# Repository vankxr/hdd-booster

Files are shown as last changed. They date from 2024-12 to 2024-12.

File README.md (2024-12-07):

# hdd-booster
This project consists of a simple PCB with two switching step-down regulators.
It aims to solve, or at least mitigate the low +5V rail current capacity of newer ATX consumer power supplies, which is a problem when trying to power lots of HDDs.
This problem is aggravated when adapters and splitters are used to expand the number of SATA/Molex power connectors.

## Short description
The board accepts power via a PCIe +12V aux power connector.
Since this board is best used on a NAS, typically there won't be any GPU installed, and thus there will be a +12V PCIe connector available.
The 12V from the PSU feeds both step-down regulators. Each regulator is capable of supplying about 5A, which should be enough for 4 power hungry HDDs.

## Authors

* **João Silva** - [vankxr](https://github.com/vankxr)

## License

The content of this repository is licensed under the [GNU General Public License v3.0](LICENSE).

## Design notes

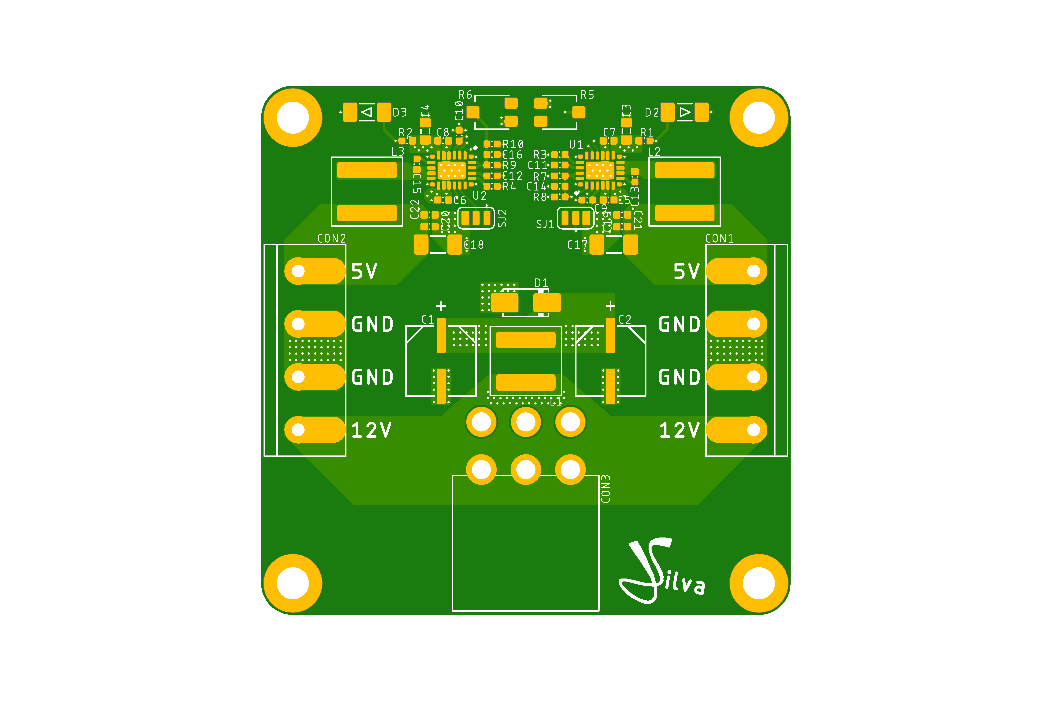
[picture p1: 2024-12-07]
pcb/hdd-booster-top.png

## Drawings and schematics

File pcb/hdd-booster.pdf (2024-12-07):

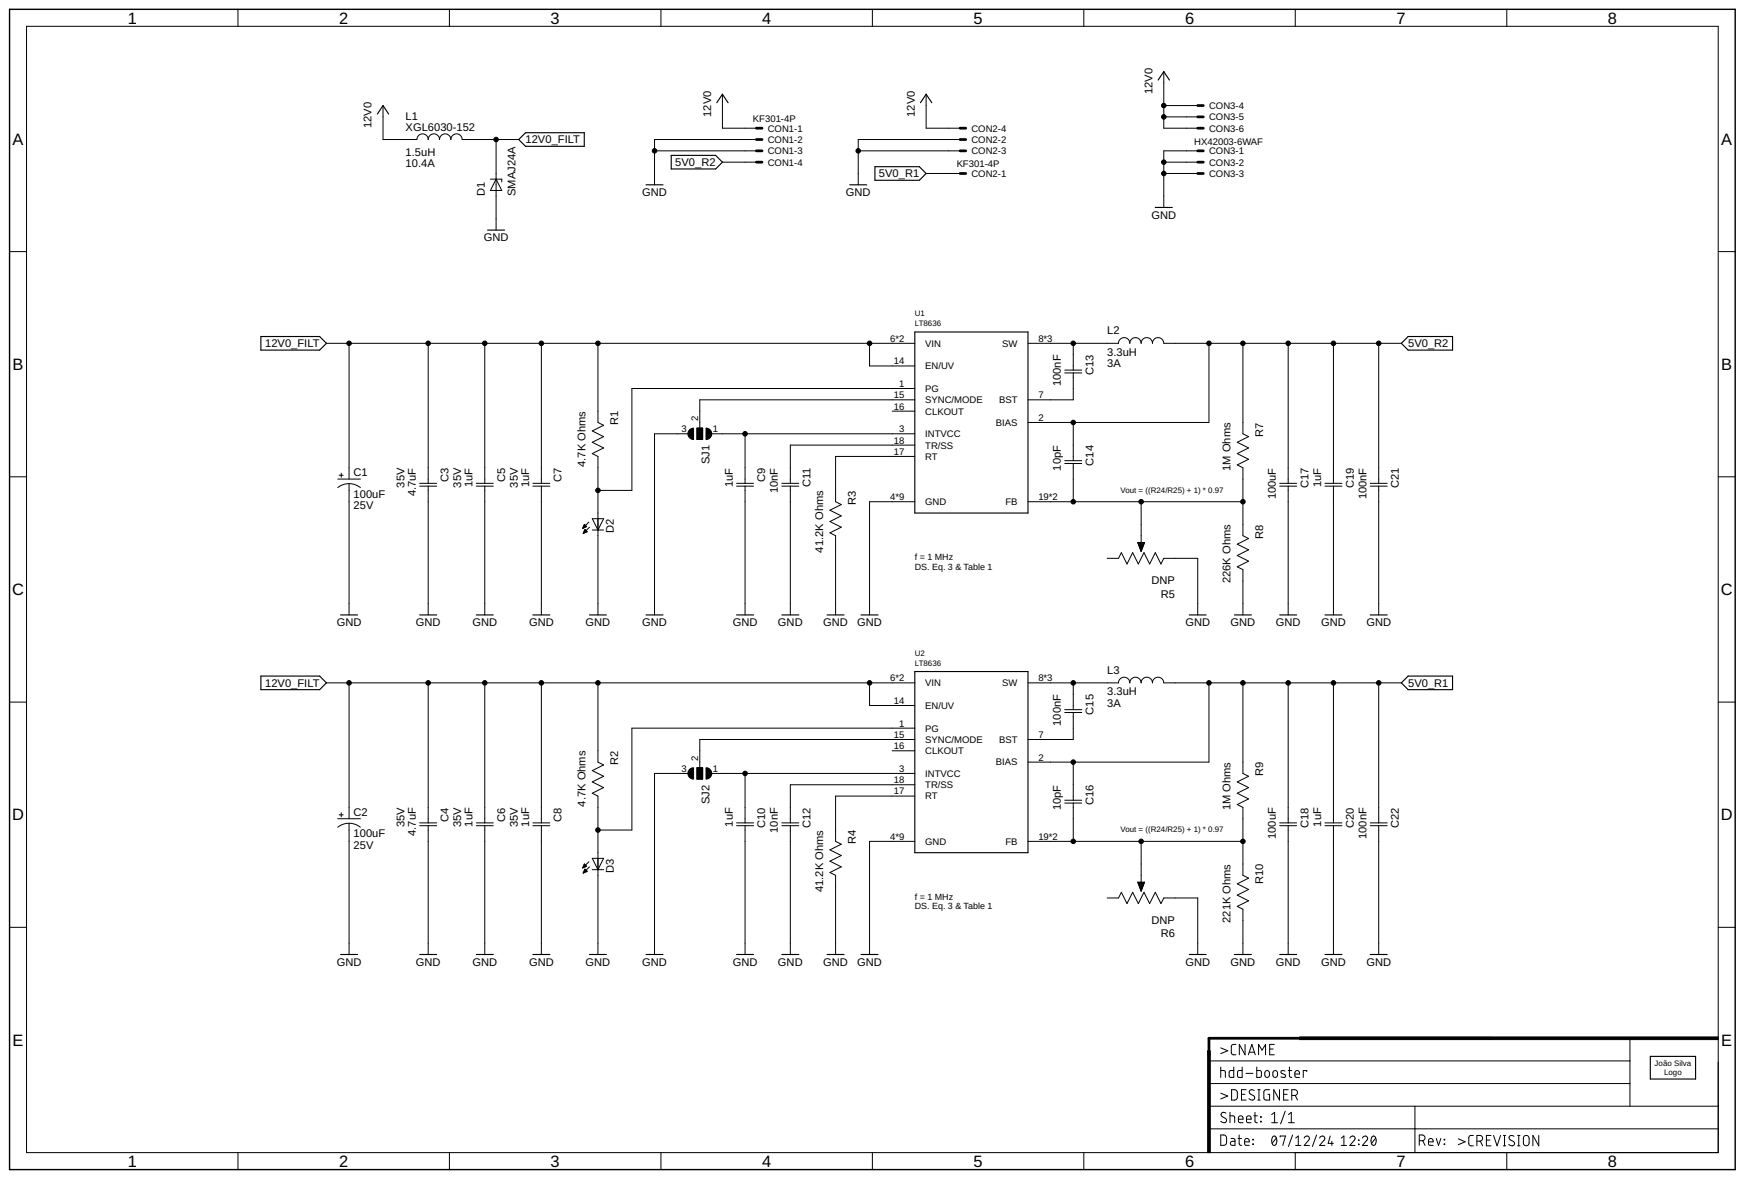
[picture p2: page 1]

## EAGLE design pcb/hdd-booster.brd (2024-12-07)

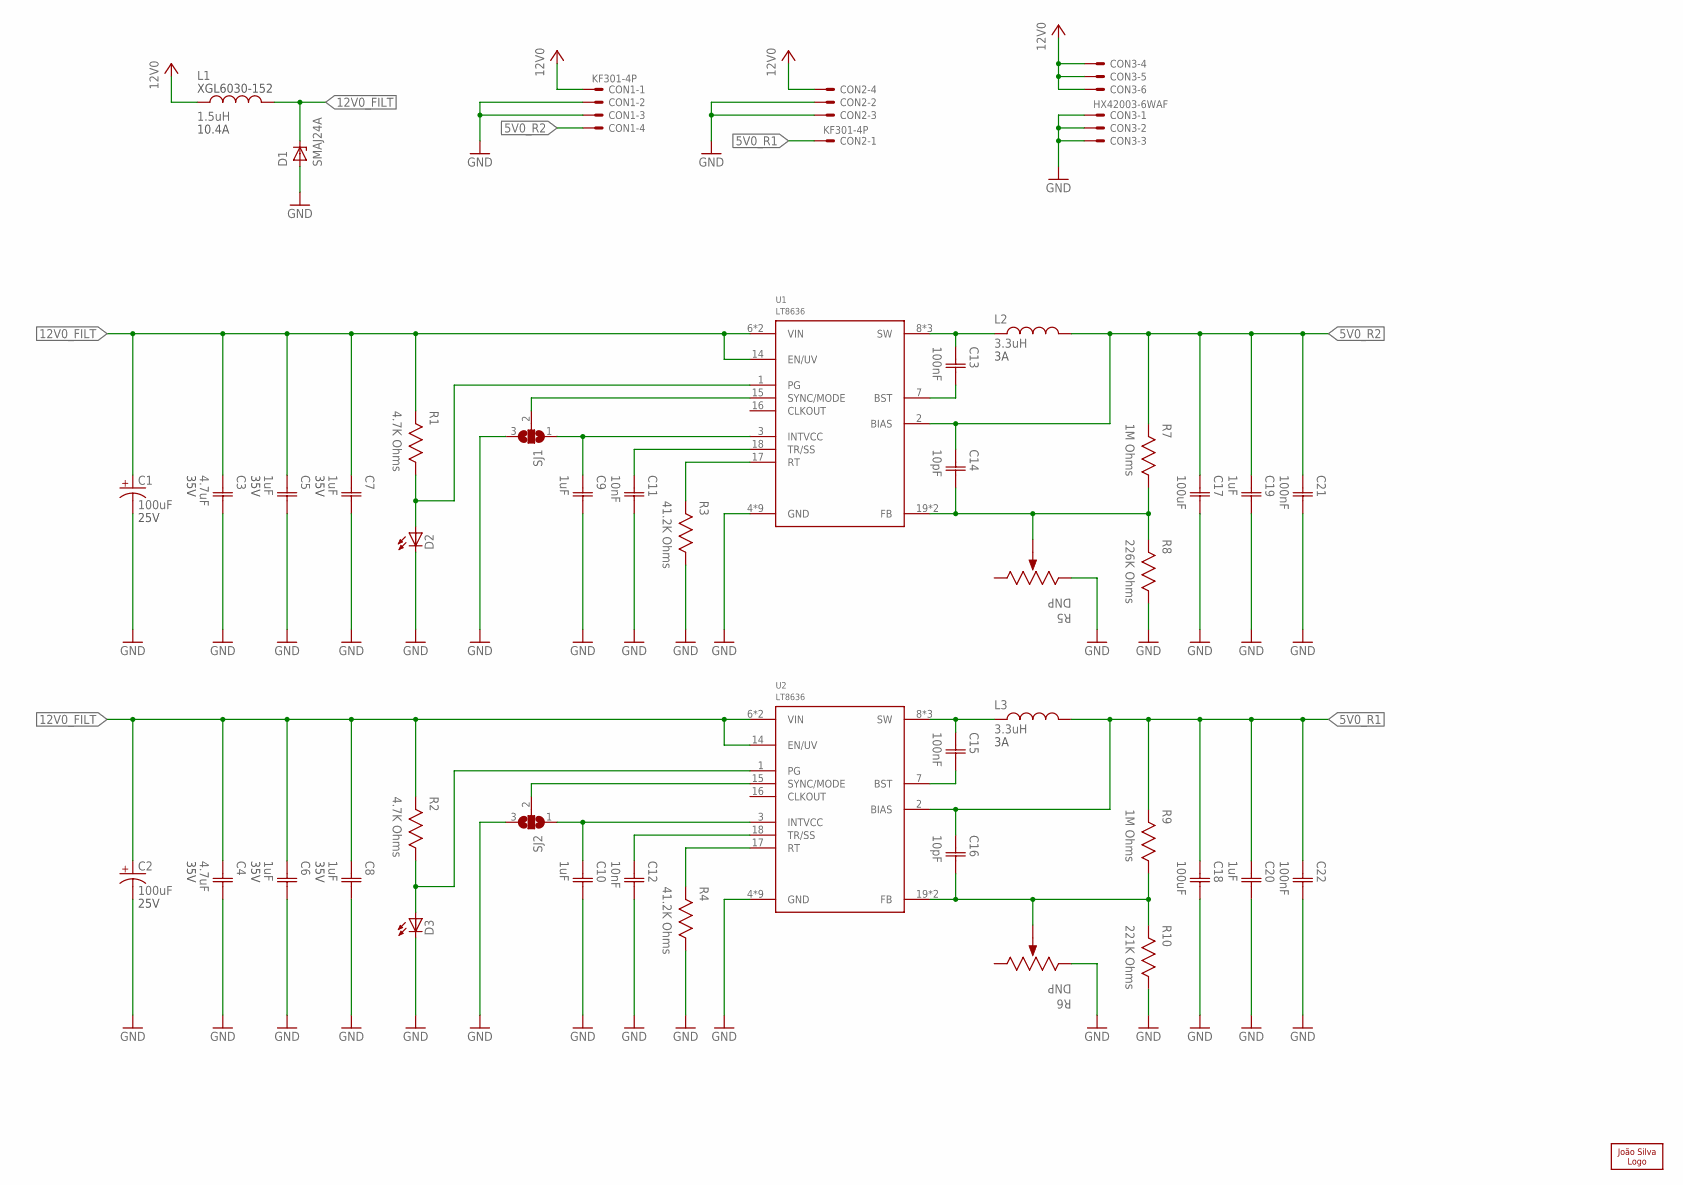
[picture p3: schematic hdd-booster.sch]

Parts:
C1, C2: 100uF; AL-CAP-CASE-D; VOLTAGE 25V
C3, C4: 4.7uF; CAP0603; VOLTAGE 35V
C5, C6, C7, C8: 1uF; CAP0402; VOLTAGE 35V
C9, C10, C19, C20: 1uF; CAP0402
C11, C12: 10nF; CAP0402
C13, C15, C21, C22: 100nF; CAP0402
C14, C16: 10pF; CAP0402
C17, C18: 100uF; CAP1206
CON1, CON2: KF301-4P
CON3: HX42003-6WAF
D1: SMAJ24A; DO214AC
D2, D3: LED1206; 1206
L1: 1.5uH; XGL6030
L2, L3: 3.3uH; XGL6030
LOGO1: JSILVA-5MM; JSILVA_5MM
R1, R2: 4.7K Ohms; RES0402
R3, R4: 41.2K Ohms; RES0402
R5, R6: DNP; POT3MM
R7, R9: 1M Ohms; RES0402
R8: 226K Ohms; RES0402
R10: 221K Ohms; RES0402
SJ1, SJ2: SJ2S; SJ2_S
U1, U2: LT8636; QFN20_ASYM_3X4_CORNER

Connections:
5V0_R1: C16.1 (C1), C18.1 (C1), C20.1 (C1), C22.1 (C1), CON2.1, L3.2, R9.2, U2.2 (BIAS)
5V0_R1_BST: C15.2 (C2), U2.7 (BST)
5V0_R1_FB: C16.2 (C2), R6.2 (WIPER), R9.1, R10.2, U2.19 (FB), U2.20 (FB)
5V0_R1_INTVCC: C10.1 (C1), SJ2.1, U2.3 (INTVCC)
5V0_R1_MODE: SJ2.2, U2.15 (SYNC/MODE)
5V0_R1_PG: D3.A, R2.1, U2.1 (PG)
5V0_R1_RT: R4.2, U2.17 (RT)
5V0_R1_SS: C12.1 (C1), U2.18 (TR/SS)
5V0_R1_SW: C15.1 (C1), L3.1, U2.8 (SW), U2.9 (SW), U2.10 (SW)
5V0_R2: C14.1 (C1), C17.1 (C1), C19.1 (C1), C21.1 (C1), CON1.4, L2.2, R7.2, U1.2 (BIAS)
5V0_R2_BST: C13.2 (C2), U1.7 (BST)
5V0_R2_FB: C14.2 (C2), R5.2 (WIPER), R7.1, R8.2, U1.19 (FB), U1.20 (FB)
5V0_R2_INTVCC: C9.1 (C1), SJ1.1, U1.3 (INTVCC)
5V0_R2_MODE: SJ1.2, U1.15 (SYNC/MODE)
5V0_R2_PG: D2.A, R1.1, U1.1 (PG)
5V0_R2_RT: R3.2, U1.17 (RT)
5V0_R2_SS: C11.1 (C1), U1.18 (TR/SS)
5V0_R2_SW: C13.1 (C1), L2.1, U1.8 (SW), U1.9 (SW), U1.10 (SW)
12V0: CON1.1, CON2.4, CON3.4, CON3.5, CON3.6, L1.1
12V0_FILT: C1.1 (+), C2.1 (+), C3.1 (C1), C4.1 (C1), C5.1 (C1), C6.1 (C1), C7.1 (C1), C8.1 (C1), D1.C, L1.2, R1.2, R2.2, U1.6 (VIN), U1.11 (VIN), U1.14 (EN/UV), U2.6 (VIN), U2.11 (VIN), U2.14 (EN/UV)
GND: C1.2 (-), C2.2 (-), C3.2 (C2), C4.2 (C2), C5.2 (C2), C6.2 (C2), C7.2 (C2), C8.2 (C2), C9.2 (C2), C10.2 (C2), C11.2 (C2), C12.2 (C2), C17.2 (C2), C18.2 (C2), C19.2 (C2), C20.2 (C2), C21.2 (C2), C22.2 (C2), CON1.2, CON1.3, CON2.2, CON2.3, CON3.1, CON3.2, CON3.3, D1.A, D2.C, D3.C, R3.1, R4.1, R5.1 (CCW), R6.1 (CCW), R8.1, R10.1, SJ1.3, SJ2.3, U1.4 (GND), U1.5 (GND), U1.12 (GND), U1.13 (GND), U1.21 (GND), U1.M1 (GND), U1.M2 (GND), U1.M3 (GND), U1.M4 (GND), U2.4 (GND), U2.5 (GND), U2.12 (GND), U2.13 (GND), U2.21 (GND), U2.M1 (GND), U2.M2 (GND), U2.M3 (GND), U2.M4 (GND)

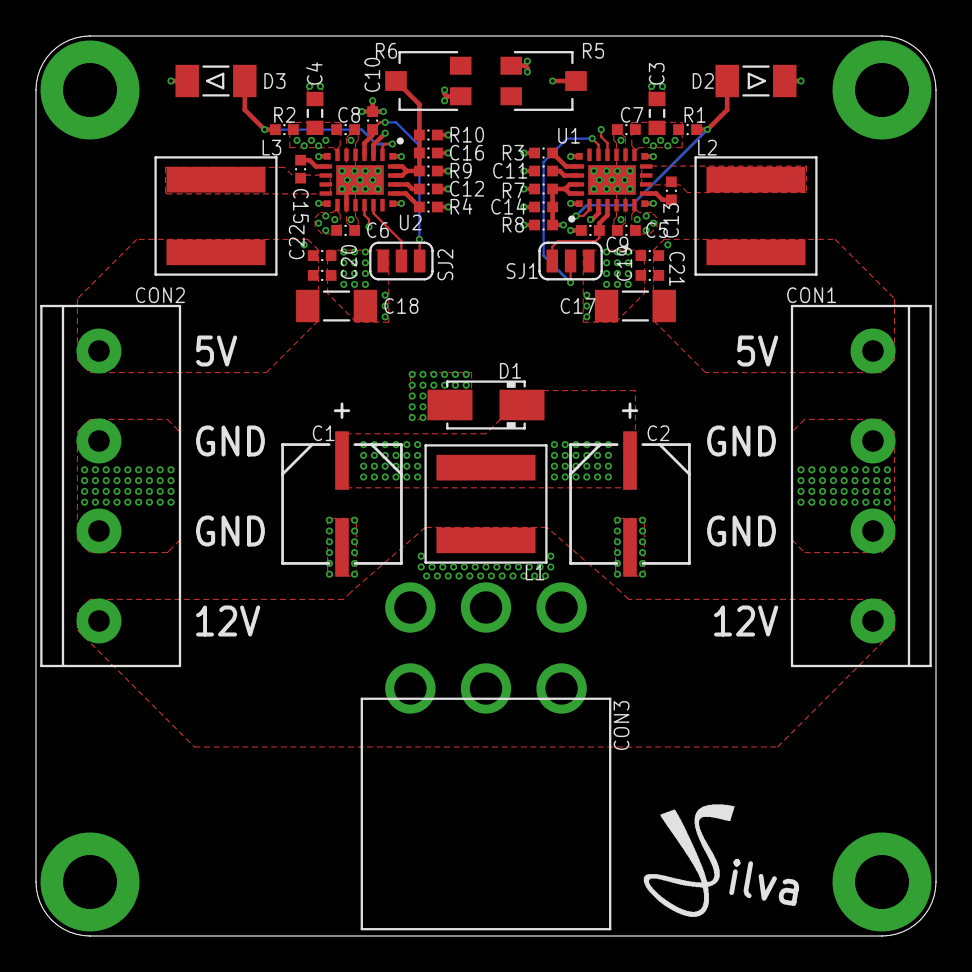
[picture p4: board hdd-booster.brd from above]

Board: 8 copper layers, 50.0 x 50.0 mm, 46 parts (0 on the bottom side), 21 nets.
